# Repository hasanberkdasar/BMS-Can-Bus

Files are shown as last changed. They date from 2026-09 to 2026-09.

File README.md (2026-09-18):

#  Smart BMS (BQ76952 & STM32F103) — 4S Lithium Battery Management System

##  About The Project & Personal Context
This project is an open-source **4S Smart Battery Management System (BMS)** designed around the **Texas Instruments BQ76952** Analog Front-End (AFE) and an **STM32F103C8T6** microcontroller. 

As a **1st-year Electrical and Electronics Engineering student**, this project represents my very first custom PCB design experience. It was built purely as a personal prototype, a learning step, and a hands-on exploration of power electronics and embedded hardware design. Because of my beginner level, the schematic and layout might appear complex, unoptimized, or messy in certain areas—it was developed as a continuous trial-and-error learning path.

---

## ⚠️ Important Engineering Note: Scaling Down from 100A to 5A

* **Original Scope vs. Current Reality:** The initial goal was to build a high-power 100A continuous BMS. However, as the design progressed, I realized that managing thermal dissipation and routing high-current copper paths properly on a standard 2-layer PCB exceeded my current technical expertise. 
* **Current Power Rating:** To keep the design safe and realistic, the continuous current rating has been officially scaled down to **5A continuous (15A peak)** for this version.
* **Why Some Traces Look Unusually Large:** You will notice that certain power paths on the board are disproportionately wide for a 5A system. These are remnants of the original 100A power path layout attempts.
* **Tested Status:** Please note that **this design has NOT been physically fabricated or hardware-tested**. It exists purely as a CAD/EDA design file.
* **Future Outlook:** The project is temporarily put on hold. Once I gain further engineering experience and technical proficiency, I plan to revisit this project to optimize thermal management and push the layout to support 100A peak and 50–60A continuous power on a computer simulation environment.

---

##  Architecture & Component Selection

### 1. Topology Selection (4S System)
A 4-series (4S) Lithium-ion / LiFePO4 configuration was selected as it matches standard low-voltage applications (such as 12V system upgrades, small EVs, or robotics power distribution) while offering a safe voltage range for learning.

### 2. Key Components & Selection Rationale
* **Texas Instruments BQ76952 (AFE):** Chosen for its highly integrated cell monitoring, hardware-level overvoltage/undervoltage protection, and flexible low-side/high-side FET drive capabilities.
* **STM32F103C8T6 (MCU):** Used as the primary host controller to read telemetry data via I2C/SMBus from the BQ76952, execute custom BMS logic, and manage external communications.
* **SN65HVD230 (CAN Transceiver):** Selected to convert the MCU's UART/CAN signals into a robust differential CAN-bus signal, making the BMS compatible with industrial and automotive telemetry networks.
* **NTC Thermistors:** External thermistor headers are added for real-time thermal monitoring of the battery pack and power MOSFETs.

---

##  Circuit Interconnections & Features

* **Power Path:** Utilizes dual-layer 2mm copper traces with a high-side back-to-back MOSFET pair (paralleled discharge/charge FETs) for battery isolation, and a low-side shunt resistor for current sensing.
* **Noise Immunity & Layout:** Decoupling capacitors are placed in immediate proximity to the power pins of both the AFE and MCU. The 8MHz crystal load capacitors are locked close to the oscillator pins.
* **EMC Shielding:** Top and bottom layers are encased with a solid Ground (GND) polygon pour for noise suppression.
* **Communication Interface:** Dedicated CAN-Bus interface pins enable continuous telemetry streaming (cell voltages, pack current, temperatures, and fault flags) to external dashboards or vehicle control units (VCU).

xx2

xx1

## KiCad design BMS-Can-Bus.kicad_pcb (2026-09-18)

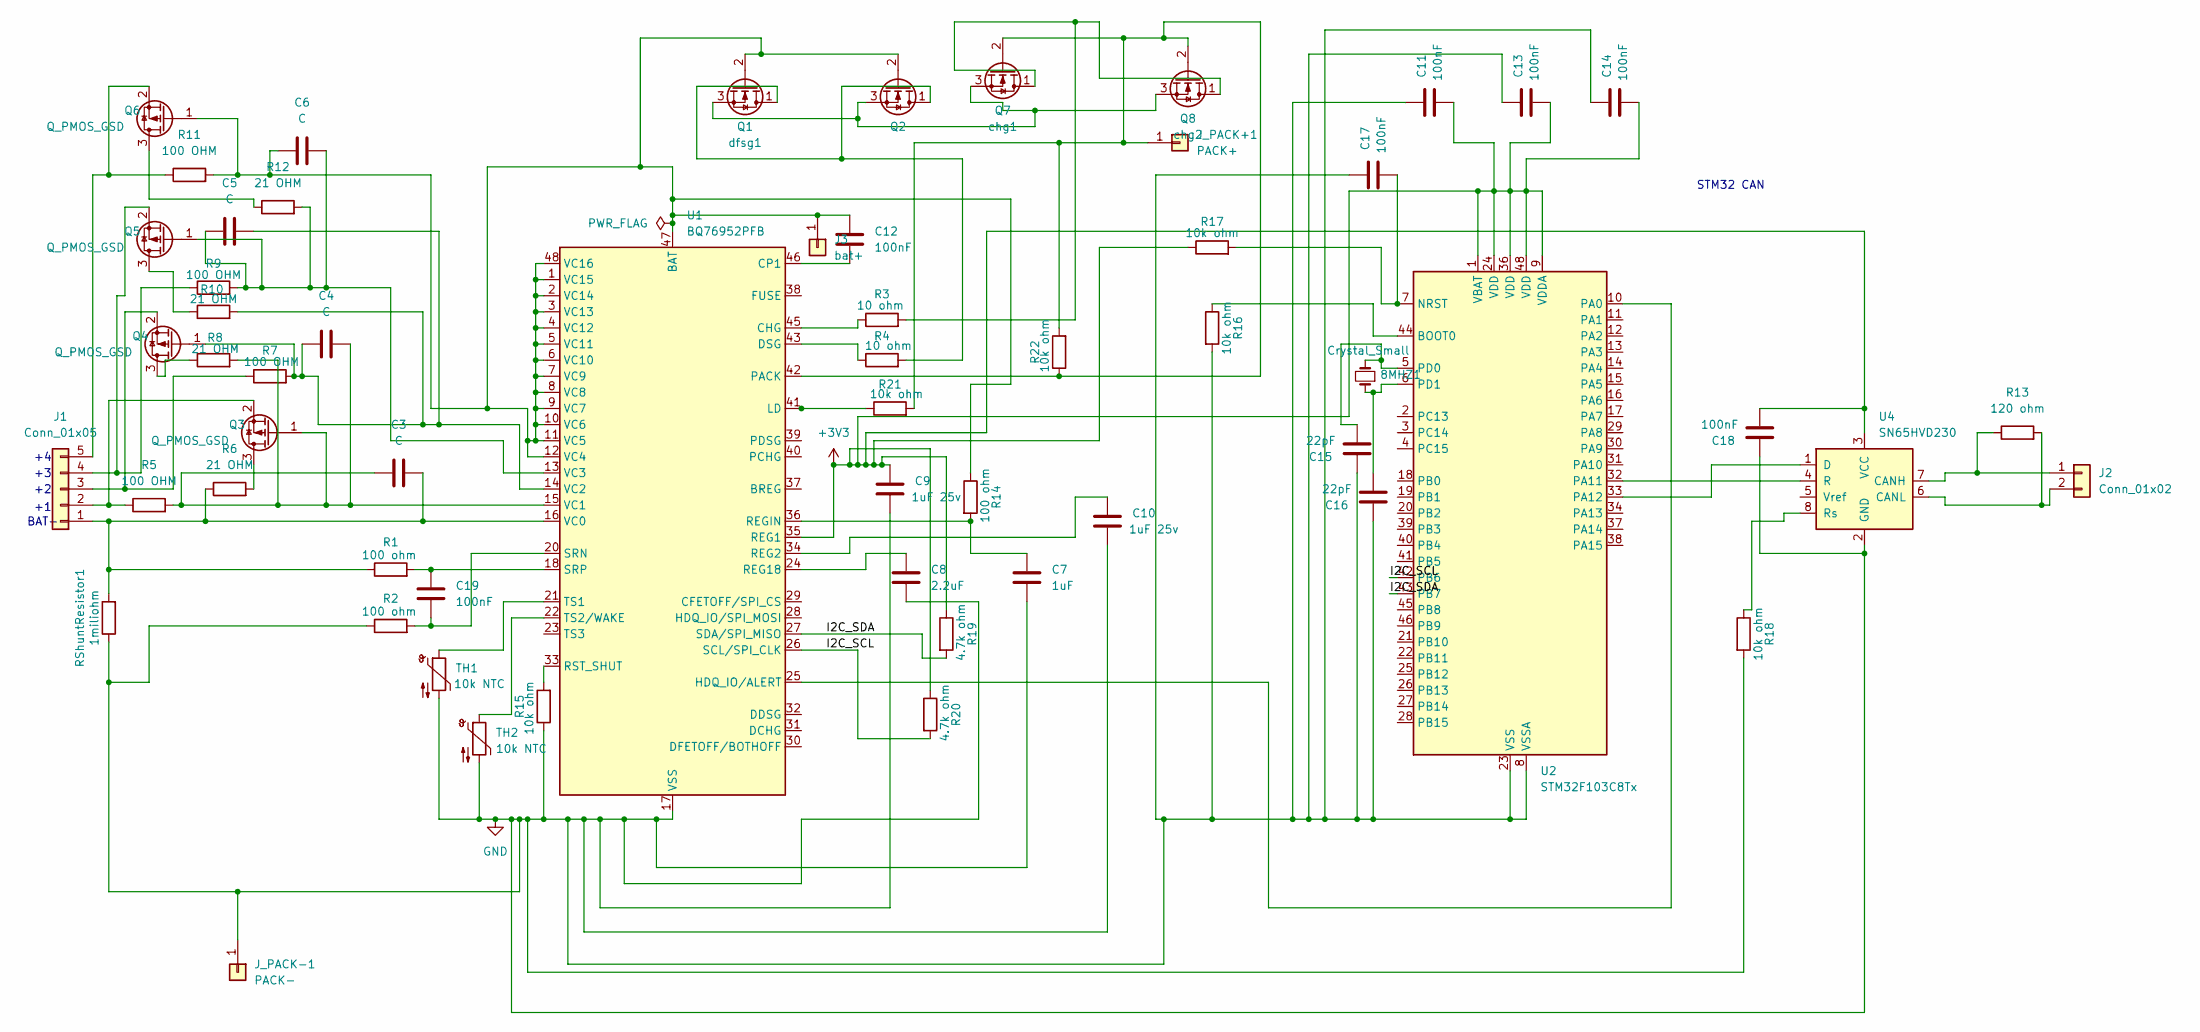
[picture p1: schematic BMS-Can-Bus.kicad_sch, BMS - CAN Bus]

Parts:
8MHZ1: Crystal_Small; Crystal_HC49-4H_Vertical
C3, C4, C5, C6: C; C_0603_1608Metric
C7: 1uF; C_0603_1608Metric
C8: 2.2uF; C_0603_1608Metric
C9, C10: 1uF 25v; C_0603_1608Metric
C11, C12, C13, C14, C17, C18, C19: 100nF; C_0603_1608Metric
C15, C16: 22pF; C_0603_1608Metric
J1: Conn_01x05; PinHeader_1x05_P2.54mm_Vertical
J2: Conn_01x02; PinHeader_1x02_P2.54mm_Vertical
J3: bat+; MountingHole_3.2mm_M3_Pad
J_PACK+1: PACK+; MountingHole_5.3mm_M5_Pad
J_PACK-1: PACK-; MountingHole_5.3mm_M5_Pad
Q1: dfsg1; TO-263-2
Q2: dsg2; TO-263-2
Q3, Q4, Q5, Q6: Q_PMOS_GSD; TO-220-3_Vertical
Q7: chg1; TO-263-2
Q8: chg2; TO-263-2
R1, R2, R14: 100 ohm; R_0805_2012Metric
R3, R4: 10 ohm; R_0805_2012Metric
R5, R7, R9, R11: 100 OHM; R_0603_1608Metric
R6, R8, R10, R12: 21 OHM; R_2512_6332Metric
R13: 120 ohm; R_0805_2012Metric
R15, R16, R17, R18, R21, R22: 10k ohm; R_0805_2012Metric
R19, R20: 4.7k ohm; R_0805_2012Metric
RShuntResistor1: 1miliohm; R_Axial_DIN0414_L11.9mm_D4.5mm_P25.40mm_Horizontal
TH1, TH2: 10k NTC; PinHeader_1x02_P2.54mm_Vertical
U1: BQ76952PFB; TQFP-48_7x7mm_P0.5mm
U2: STM32F103C8Tx; LQFP-48_7x7mm_P0.5mm
U4: SN65HVD230; SOIC-8_3.9x4.9mm_P1.27mm

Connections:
+3V3: C9.2, C11.1, C13.1, C14.1, C18.1, R17.1, R19.1, R20.1, U1.35 (REG1), U2.1 (VBAT), U2.9 (VDDA), U2.24 (VDD), U2.36 (VDD), U2.48 (VDD), U4.3 (VCC)
/I2C_SCL: R20.2, U1.26 (SCL/SPI_CLK), U2.42 (PB6)
/I2C_SDA: R19.2, U1.27 (SDA/SPI_MISO), U2.43 (PB7)
GND: C7.1, C8.1, C9.1, C10.1, C11.2, C13.2, C14.2, C15.2, C16.2, C17.2, C18.2, J_PACK-1.1 (Pin_1_1), R2.1, R15.1, R16.2, R18.2, RShuntResistor1.1, TH1.2, TH2.2, U1.17 (VSS), U2.8 (VSSA), U2.23 (VSS), U2.35 (VSS), U2.47 (VSS), U4.2 (GND)
unnamed: C3.2, J1.1, R1.1, R6.1, RShuntResistor1.2, U1.16 (VC0)
unnamed: J1.2, Q3.2 (S), R5.1
unnamed: J1.3, Q4.2 (S), R7.1
unnamed: J1.4, Q5.2 (S), R9.1
unnamed: J1.5, Q6.2 (S), R11.1
unnamed: J2.1, R13.1, U4.7 (CANH)
unnamed: J2.2, R13.2, U4.6 (CANL)
unnamed: C6.1, C12.2, J3.1 (Pin_1_1), Q1.2 (G), Q2.2 (G), Q6.1 (G), R11.2, R14.1, U1.1 (VC15), U1.2 (VC14), U1.3 (VC13), U1.4 (VC12), U1.5 (VC11), U1.6 (VC10), U1.7 (VC9), U1.8 (VC8), U1.9 (VC7), U1.10 (VC6), U1.11 (VC5), U1.12 (VC4), U1.47 (BAT), U1.48 (VC16)
unnamed: J_PACK+1.1 (Pin_1_1), Q7.2 (G), Q8.2 (G), R21.2, R22.1, R22.2, U1.42 (PACK)
unnamed: Q1.1 (D), Q2.1 (D), R4.2
unnamed: Q1.3 (S), Q2.3 (S), Q7.3 (S), Q8.3 (S)
unnamed: Q3.3 (D), R6.2
unnamed: C3.1, C4.2, Q3.1 (G), R5.2, R8.2, U1.15 (VC1)
unnamed: Q4.3 (D), R8.1
unnamed: C4.1, C5.2, Q4.1 (G), R7.2, R10.2, U1.14 (VC2)
unnamed: Q5.3 (D), R10.1
unnamed: C5.1, C6.2, Q5.1 (G), R9.2, R12.2, U1.13 (VC3)
unnamed: Q6.3 (D), R12.1
unnamed: Q7.1 (D), Q8.1 (D), R3.2
unnamed: R3.1, U1.45 (CHG)
unnamed: C12.1, U1.46 (CP1)
unnamed: R4.1, U1.43 (DSG)
unnamed: U1.25 (HDQ_IO/ALERT), U2.10 (PA0)
unnamed: R21.1, U1.41 (LD)
unnamed: C10.2, U1.34 (REG2)
unnamed: C8.2, U1.24 (REG18)
unnamed: C7.2, R14.2, U1.36 (REGIN)
unnamed: R15.2, U1.33 (RST_SHUT)
unnamed: C19.1, R2.2, U1.20 (SRN)
unnamed: C19.2, R1.2, U1.18 (SRP)
unnamed: TH1.1, U1.21 (TS1)
unnamed: TH2.1, U1.22 (TS2/WAKE)
unnamed: R16.1, U2.44 (BOOT0)
unnamed: C17.1, R17.2, U2.7 (NRST)
unnamed: U2.32 (PA11), U4.4 (R)
unnamed: U2.33 (PA12), U4.1 (D)
unnamed: 8MHZ1.2, C15.1, U2.5 (PD0)
unnamed: 8MHZ1.1, C16.1, U2.6 (PD1)
unnamed: R18.1, U4.8 (Rs)

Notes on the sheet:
STM32 CAN
BAT-

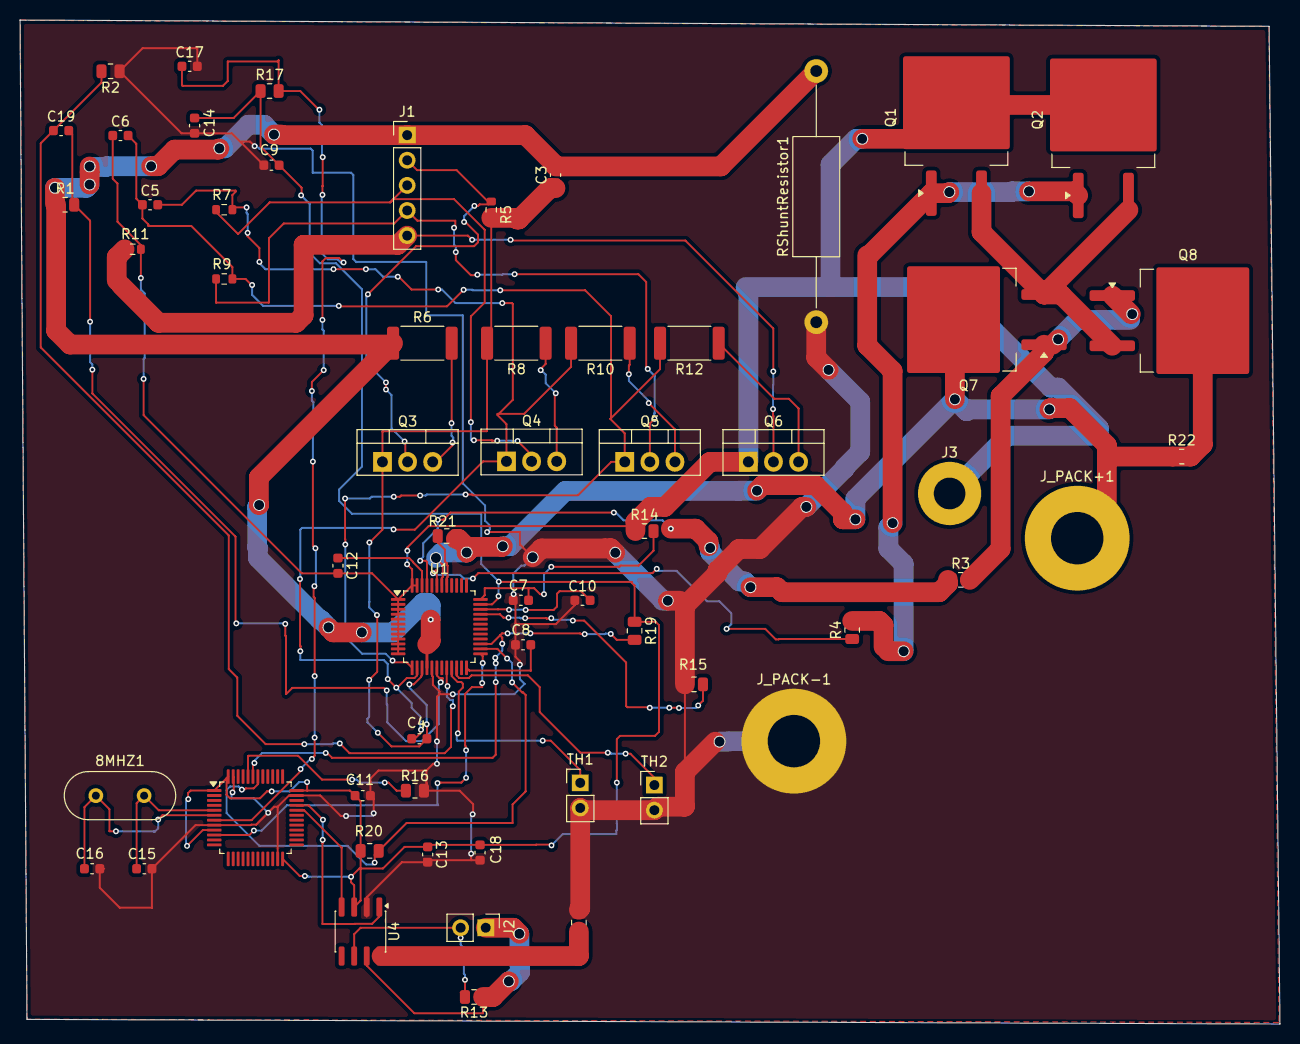
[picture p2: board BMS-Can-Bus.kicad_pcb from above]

Board: 2 copper layers, 127.4 x 101.5 mm, 59 parts (0 on the bottom side), 43 nets.

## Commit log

2026-09-16 Add README with project description and component details
    Added project overview and details about components used for the smart BMS hardware design.
2026-09-16 Add files via upload
    Added STM32 and CAN Bus communication to schematic and PCB.
    [BMS-Can-Bus.kicad_pcb, BMS-Can-Bus.kicad_sch]
2026-09-16 Complete STM32 & CAN Bus integration
    100A Smart BMS hardware schematics and PCB layout design completed with zero DRC errors.
    Key Changes & Technical Implementation:
    ----------------------------------------
    1. STM32F103 Power Supply & Filtering:
    - Tied VBAT, VDD (Pins 24, 36, 48), and VDDA (Pin 9) directly to BQ76952 REG1 (+3V3).
    - Connected VSS (Pin 23) and VSSA (Pin 8) to GND.
    - Added 100nF decoupling capacitors parallel across each VDD-GND pair.
    2. HSE Clock, Reset & Boot Configuration:
    - Connected 8MHz external crystal (Y1) across PD0 (Pin 5) and PD1 (Pin 6) with 2x 22pF load capacitors to GND.
    - Configured NRST (Pin 7) with 100nF filter capacitor to GND and 1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
    [BMS-Can-Bus.kicad_pcb, BMS-Can-Bus.kicad_sch]
2026-09-16 Revise README for clarity and structure
    Updated README to provide clearer project details, component selection rationale, and PCB design status. Removed redundant sections and improved overall structure for better readability.
2026-09-16 critical hardware blockers & BQ76952 connections
    Applied essential hardware fixes and schematic revisions:
    - Linked BQ76952 I2C lines (SDA/SCL) to STM32 (PB6/PB7) with net labels.
    - Corrected shunt resistor differential sense connections (SRP/SRN) and added 100nF filter capacitor (C19).
    - Added 100nF charge pump capacitor to CP1 pin (Pin 46) for high-side MOSFET driving.
    - Added PACK+ connector terminal (J_PACK+1) to the charge/discharge MOSFET output chain.
    - Cleaned up CAN transceiver configuration to standard 3.3V SN65HVD230 (U4).
    - Prepared high-current power path nodes for 100A polygon fill/copper zones on PCB layout.
    [BMS-Can-Bus.kicad_pcb, BMS-Can-Bus.kicad_sch]
2026-09-17 shunt resistor bypass add PACK+/- connectors pass DRC
    - Fixed shunt resistor bypass issue by isolating BAT- from main GND and properly connecting SRP/SRN Kelvin sense traces.
    - Connected PACK+ output terminal to power MOSFETs and routed PACK (Pin 42) & LD (Pin 41) sensing pins with 10k ohm series resistors.
    - Added PACK- output connector connected directly to the system GND side of the current shunt.
    - Updated PCB netlist from schematic and resolved all DRC short-circuit violations (0 errors, 0 warnings).
    [BMS-Can-Bus.kicad_pcb, BMS-Can-Bus.kicad_sch]
2026-09-17 Optimize PCB layout and power paths
    High-current power paths refactored, decoupling capacitors optimized, and GND polygon pour added.
    [BMS-Can-Bus.kicad_pcb]
2026-09-17 docs: update specification to 5A continuous rating and finalize layout
    update specification to 5A continuous rating and finalize layout
    [BMS-Can-Bus.kicad_pcb]
2026-09-17 Revise README for Smart BMS project details
    Updated project description and context for the Smart BMS, including component selection rationale and current power rating adjustments. Added important engineering notes regarding design limitations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
2026-09-17 Update Power Path description in README
    Enhanced the description of the Power Path feature for clarity and detail.
2026-09-18 ERC warnning
    Known open items: 2 ERC warnings remain unresolved (a GND net junction and the LD pin pull-up connection near R21) — likely a wire/grid-snap issue in the schematic editor that I couldn't fully trace. Flagging as a known limitation for this learning-stage design.
    [BMS-Can-Bus.kicad_pcb, BMS-Can-Bus.kicad_sch]
2026-09-18 Add files via upload
    redesign PCB size
    [BMS-Can-Bus.kicad_pcb]
2026-09-18 refactor(pcb): reduce board size and increase power trace widths to 2mm
    [BMS-Can-Bus.kicad_pcb]
